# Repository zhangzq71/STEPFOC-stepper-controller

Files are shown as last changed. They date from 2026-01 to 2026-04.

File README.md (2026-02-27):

# STEPFOC Stepper controller

  



## 📖 Project Overview

**STEPFOC** is a FOC based stepper motor controller designed to deliver affordable, high-performance hardware paired with powerful open-source software. Its mission is to transform low-cost stepper motors into high-performance robotic servos, enabling advanced robotics applications without the high price tag.

The controller features a 14-bit magnetic encoder, inline current sensing, CAN and UART interfaces, and supports position, velocity, torque, and impedance control modes.

> [!NOTE]
> Optimized for NEMA17 format but it can also be attached to nema 23 and 14 steppers!

> [!IMPORTANT]
>     **STEPFOC stepper driver is built on the same hardware and software foundation as the Spectral Micro BLDC driver. As a result, some references or images in this documentation may still show the Spectral Micro, since both drivers share about 99% of their features. They also use the same CAN and UART command sets, with only minor differences in UART-based calibration and setup procedures.**

## Where to buy? 

You can buy the STEPFOC stepper controller here: <br />
 https://source-robotics.com/products/stepfoc-stepper-controller

## 💾Firmware 
STEPFOC firmware is located [here](https://github.com/PCrnjak/STEPFOC-stepper-controller/tree/main/STEPFOC%20firmware). To install it follow [this guide!](https://source-robotics.github.io/STEPFOC-docs/flashing_firmware/)

## 📚Documentation:

- [Motor hardware setup guide](https://youtu.be/60UMc95H8iE)
- [Official website](https://source-robotics.com/products/spectral-micro-bldc-controller)
- [DOCS](https://source-robotics.github.io/STEPFOC-docs/) Offers great starting guides with project examples + code 

### API and control
- [GUI software ](https://github.com/PCrnjak/Spectral-motor-GUI)
- [Python API & Examples](https://github.com/PCrnjak/Spectral-BLDC-Python/tree/main)
- [Source Robotics toolbox](https://github.com/PCrnjak/Source-Robotics-Toolbox/tree/main) 

## 🌐 More about STEPFOC drivers

| YouTube | Instagram | Twitter | LinkedIn |
|---|---|---|---|
|  |  |  |  |

| Discord | Forum | Hackaday | Blog |
|---|---|---| ---|
|  |  |  |  

## ⚠️ Safety, Liability & Disclaimer
1. The software and hardware are still in development and may contain bugs, errors, or incomplete features.
2. Users are encouraged to use this software and hardware responsibly and at their own risk.

## 💸Support us

The majority of this project is open source and freely available to everyone. Your assistance, whether through donations or advice, is highly valued. Thank you!

 


## 🛡️ Licensing

Project is under GPLv3 Licence

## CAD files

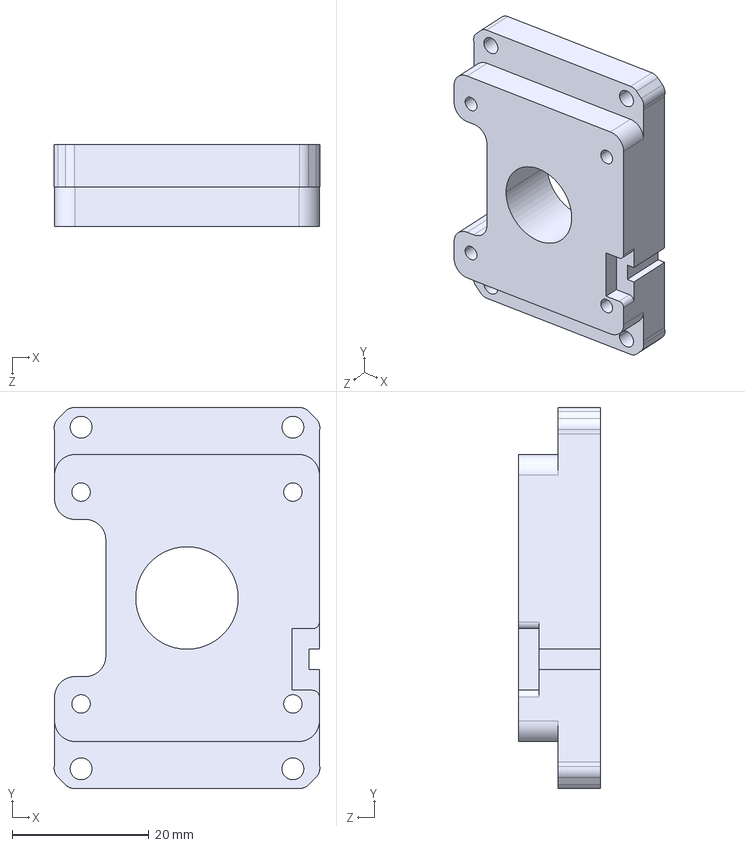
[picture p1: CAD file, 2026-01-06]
STEP files/Stepper motor accessories/NEMA23/NEMA23_stepper_spacer.STEP
38.9 x 55.8 x 12.0 mm

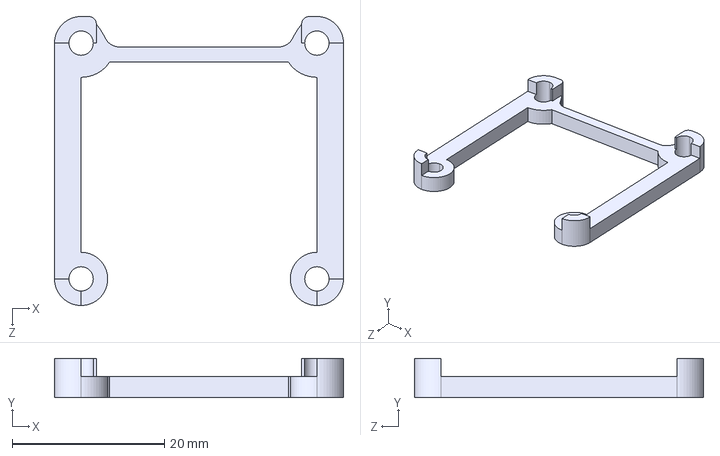
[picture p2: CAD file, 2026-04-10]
STEP files/Stepper motor accessories/Stepper_spacer_NEMA17_21_5mm.STEP
38.0 x 5.15 x 38.0 mm

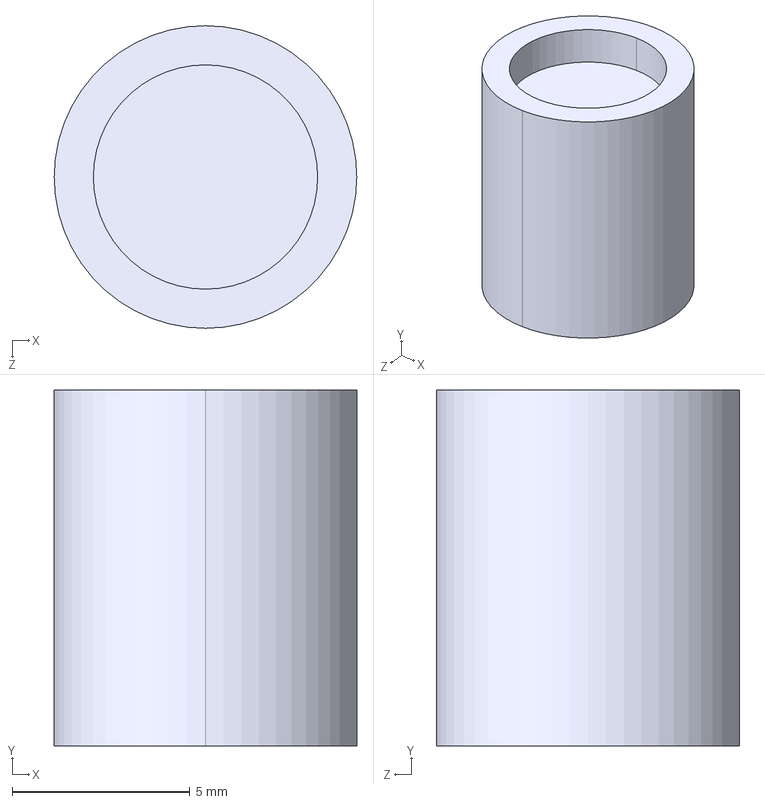
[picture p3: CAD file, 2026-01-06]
STEP files/Tools/Magnet_stepper_tool.STEP
8.50 x 10.0 x 8.50 mm

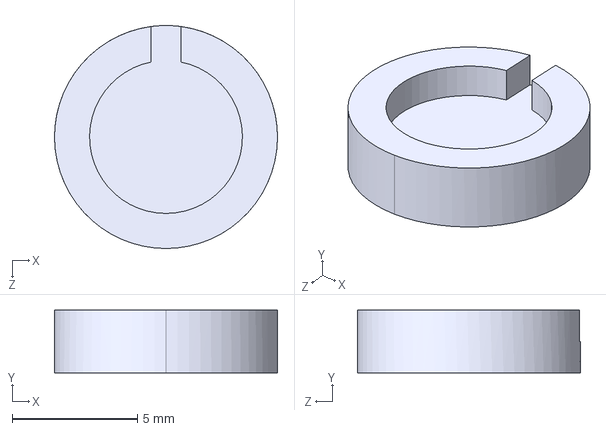
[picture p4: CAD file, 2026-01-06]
STEP files/Stepper motor accessories/Magnet_spacer_2.STEP
8.90 x 2.50 x 8.90 mm

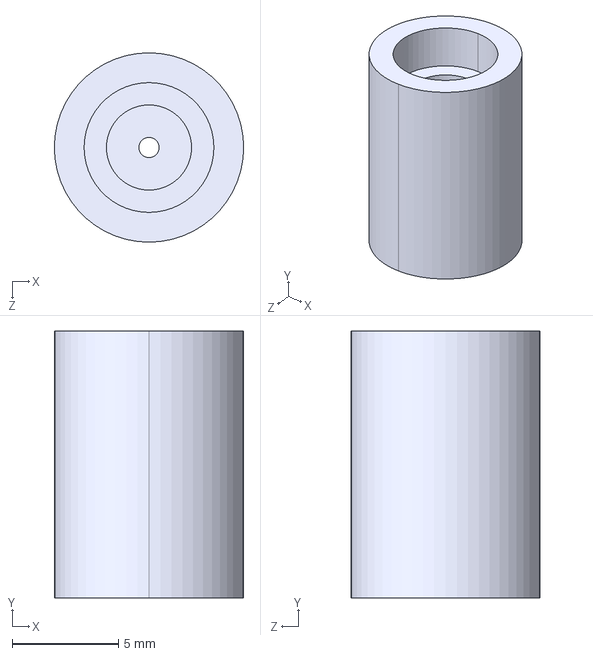
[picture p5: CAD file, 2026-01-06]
STEP files/Stepper motor accessories/NEMA23/Nema23_magnet_spacer.STEP
8.90 x 12.6 x 8.90 mm

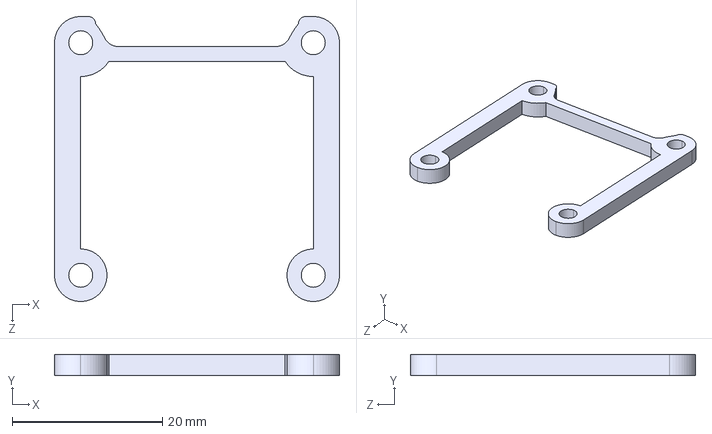
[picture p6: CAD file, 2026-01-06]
STEP files/Stepper motor accessories/Stepper_spacer_NEMA17.STEP
38.0 x 2.80 x 38.0 mm

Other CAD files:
STEP files/Tools/Magnet_stepper_tool_v2.STEP

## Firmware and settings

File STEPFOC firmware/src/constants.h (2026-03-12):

/* USER CODE BEGIN Header */
/**
 ******************************************************************************
 * @file    constants.h
 * @brief   This file provides code where we declare constants
 * @author Petar Crnjak
 ******************************************************************************
 * @attention
 *
 * Copyright (c) Source robotics.
 * All rights reserved.
 *
 * This software is licensed under terms that can be found in the LICENSE file
 * in the root directory of this software component.
 * If no LICENSE file comes with this software, it is provided AS-IS.
 *
 ******************************************************************************
 */

/* Define to prevent recursive inclusion -------------------------------------*/
#ifndef CONSTANTS_H
#define CONSTANTS_H

#define MAX_DRIVE_CURRENT 2800 // 2500 mA

#define MT6816_NO_MAGNET_BIT 0x0002

#define MAX_DUTY 0.95f

#define MIN_DUTY 0.05f

#define OVERMODULATION 1 // 1 no overmodulation, 1.154F SPWM overmodulation

#define ADC_RESOLUTION_ 12

#define MAX_TEMPERATURE 80

#define PI 3.14159265359f

#define PI2 6.283185307f

#define SQRT3DEV2 0.8660254038f

#define CPR 16384

#define RAD_CONST 0.000383495187f

#define CPR2 16384 / 2

#define MIN_VOLTAGE

#define PWM_FREQ 25000

#define LOOP_FREQ 6250 

#define LOOP_TIME 0.00016

#define CLOCK_PRESCALE 14

#define SERIAL_SPEED 256000 // 256000 works, Tested with 1Mbit and works

#define SENSE_RESISTOR 0.025f

#define Rdson 0.2f // 200 miliohms

#define ADC_MIDPOINT 1.65f

#define ADC_MIDPOINT_BIT 2048

#define CURRENT_AMP_GAIN 20

#define R1_voltage 100000

#define R2_voltage 870

#define PWM_MAX 8191

#define PWM_MIN 0

/*
EEPROM CONSTANTS
*/

///// EEPROM variable address list
#define SERIAL_NUMBER_EEPROM 32
#define HARDWARE_VERSION_EEPROM 36
#define BATCH_DATA_EEPROM 40
#define CAN_ID_EEPROM 44
#define SOFTWARE_VERSION_EEPROM 48
#define LED_ON_OFF_EEPROM 52
#define THERMISTOR_ON_OFF_EEPROM 56
#define POLE_PAIR 60
#define DIR_EEPROM 64
#define RESISTANCE_EEPROM 68
#define TOTAL_RESISTANCE_EEPROM 72
#define INDUCTANCE_EEPROM 76
#define KT_EEPROM 80
#define KV_EEPROM 84
#define FLUX_LINKAGE_EEPROM 92
#define KPP_EEPROM 96
#define KPV_EEPROM 100
#define KIV_EEPROM 104
#define VELOCITY_LIMIT_EEPROM 108
#define KIIQ_EEPROM 112
#define KPIQ_EEPROM 116
#define IQ_CURRENT_LIMIT_EEPROM 120

#define KIID_EEPROM 124
#define KPID_EEPROM 128
#define ID_CURRENT_LIMIT_EEPROM 132

#define KP_EEPROM 136
#define KD_EEPROM 140
#define CALIBRATED_EEPROM 144
#define PHASE_ORDER_EEPROM 148
#define WATCHDOG_TIME_EEPROM 152
#define WATCHDOG_ACTION_EEPROM 156
#define HEARTBEAT_RATE_EEPROM 160
#define I_AM_GRIPPER_EEPROM 164
#define RESET_INTEGRAL_EEPROM 168
#define TEMPERATURE_ERROR 172
#define VOLTAGE_ERROR 176
#define VOLTAGE_LIMIT 180
#define THETA_OFFSET 184

/*
CAN BUS CONSTANTS
*/

// OUTPUT CAN command IDs (Commands that spectral driver can send)
#define OUT_HEARTBEAT 9
#define OUT_DATA_PACK_1 3
#define OUT_DATA_PACK_2 5
#define OUT_DATA_PACK_3 7
#define OUT_DATA_HALL 32 // Response to IN_HALL_INDEX

// Commands that host and driver can send. Host only with RTR frame
// Commands that have same command ID on PC and driver side by using REMOTE FRAME
// When beign sent by host they need to be sent as REMOTE FRAME
// BLDC driver then responds with data with SAME ID as the REMOTE FRAME
#define OUT_IN_TEMPERATURE_CAN 23
#define OUT_IN_VOLTAGE_CAN 24
#define OUT_IN_DEVICE_INFO_CAN 25
#define OUT_IN_STATE_OF_ERRORS_CAN 26
#define OUT_IN_IQ 27
#define OUT_IN_ENCODER 28
#define OUT_IN_PING 10
#define OUT_IN_KT 33

// INPUT CAN command IDS (Commands that spectral driver can receive)
// To these commands spectral responds nothing
#define IN_CAN_ID 11
#define IN_ESTOP 0
#define IN_IDLE 12
#define IN_SAVE_CONFIG 13
#define IN_RESET 14
#define IN_CLEAR_ERROR 1
#define IN_WATCHDOG_TIMEOUT 15
#define HEARTBEAT_SETUP 30
#define IN_CYCLIC 29

#define IN_KP_KD 16
#define IN_KIIQ_KPIQ 17
#define IN_KPV_KIV 18
#define IN_KPP 19
#define IN_LIMITS 20
#define IN_IQ 21
#define IN_KT 22

// INPUT CAN command IDS (Commands that spectral driver can receive)
// To these commands spectral responds with specific command ID
#define IN_DATA_PACK_1 2
#define IN_DATA_PACK_2 6
#define IN_DATA_PACK_3 8
#define IN_DATA_PACK_PD 4
#define IN_HALL_INDEX 31


// GRIPPER SPECIFIC COMMANDS
// OUTPUT CAN command IDs (Commands that gripper can send)
#define OUT_GRIPPER_DATA_PACK 60

// INPUT CAN command IDs (Commands that gripper can receive)
#define IN_GRIPPER_DATA_PACK 61
#define IN_GRIPPER_CALIB 62


#endif

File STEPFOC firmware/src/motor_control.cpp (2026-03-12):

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
/* Includes ------------------------------------------------------------------*/

#include "utils.h"
#include <Arduino.h>
#include <stdio.h>
#include "iodefs.h"
#include "hw_init.h"
#include "motor_control.h"
#include "common.h"
#include <SPI.h>
#include "common.h"
#include "foc.h"

#define TIMING_DEBUG 0

SPISettings MT6816_settings(16000000, MSBFIRST, SPI_MODE3);

/// @todo phase order working in any orientation
/// @todo feedforwards for cascade control and PD control
/// @todo cogging compensation
/// @todo encoder non linearity compensation

/// @brief  Collect all sensor data
void Collect_data()
{

  uint16_t result;
  uint16_t result1;
  uint16_t result2;

  /*Get position, current1, current2, vbus*/
  /*position sensor packs its data in 2 8 bit data packets */
  /*First we send 0x8300 as a response we get one packet*/
  /*Then we send 0c8400 as a response we get second packet*/
  /*Between requesting packets we need small delay and we use ADC readings as a delay*/
  /*Reading sense1,2 and vbus takes around 10us */
  /*After we get both packets they are unpacked and we get position value as 14 bit, no mag bit and parity check bit */
  SPI.beginTransaction(MT6816_settings);
  digitalWriteFast(CSN, LOW);
  result1 = SPI.transfer16(0x8300);
  digitalWriteFast(CSN, HIGH);

  controller.Sense1_Raw = ADC_CHANNEL_6_READ_SENSE1();
  controller.Sense2_Raw = ADC_CHANNEL_8_READ_SENSE2();

  controller.VBUS_RAW = ADC_CHANNEL_4_READ_VBUS();
  result1 = result1 << 8;
  digitalWriteFast(CSN, LOW);
  result2 = SPI.transfer16(0x8400);
  digitalWriteFast(CSN, HIGH);
  result = result1 | result2;
  controller.Position_Raw = (result >> 2);
  SPI.endTransaction();
  /***********************************/

  /* Check for magnet on MT6816*/
  if ((result & MT6816_NO_MAGNET_BIT) == MT6816_NO_MAGNET_BIT)
  { // no magnet or not detecting enough flux density
    controller.Magnet_warrning = true;
    controller.encoder_error = 1;
  }
  else
  { // Detected magnet
    controller.Magnet_warrning = false;
  }
  /***********************************/

  /* Parity check, works wierd and inconsistent, skip for now
 if(parityCheck(result)){
    controller.MT6816_parity_check_pass = 1;
 }else{
    controller.MT6816_parity_check_pass = 0;
 }
*/

  /* Transform RAW current and voltage to mV, mA.*/

  controller.Sense1_mA = -Get_current_mA(controller.Sense1_Raw);
  controller.Sense2_mA = Get_current_mA(controller.Sense2_Raw);

  controller.VBUS_mV = Get_voltage_mA(controller.VBUS_RAW);
  /***********************************/

  /* Handle encoder full rotation overflow*/
  if (controller.Position_Raw - controller.Old_Position_Raw > CPR2)
  {
    controller.ROTATIONS = controller.ROTATIONS - 1;
  }
  else if (controller.Position_Raw - controller.Old_Position_Raw < -CPR2)
  {
    controller.ROTATIONS = controller.ROTATIONS + 1;
  }
  /***********************************/

  /* Motor position with multiple rotations in encoder ticks*/
  controller.Position_Ticks = controller.Position_Raw + (controller.ROTATIONS * CPR);
  /***********************************/

  /* Calculate velocity in ticks/s */
  controller.Velocity = (controller.Position_Ticks - controller.Old_Position_Ticks) / LOOP_TIME;
  /* Moving average filter on the velocity */
  controller.Velocity_Filter = movingAverage(controller.Velocity);
  /***********************************/

  /*  Save position values for next cycle*/
  controller.Old_Position_Ticks = controller.Position_Ticks;
  controller.Old_Position_Raw = controller.Position_Raw;
  /***********************************/

  // Position_RAD = qfp_fmul(Position_Raw, RAD_CONST);

  /* Caclculate electrical angle */
  // controller.Electric_Angle = RAD_CONST * fmod((controller.Position_Raw * NPP),CPR);
  controller.Electric_Angle = RAD_CONST * ((controller.Position_Raw * controller.pole_pairs) % CPR);

  // add offset
  controller.Electric_Angle += controller.theta_offset;

  // Normalize angle between 0 and 2Pi
  if (controller.Electric_Angle < 0)
    controller.Electric_Angle = (controller.Electric_Angle + PI2);
  else if (controller.Electric_Angle > PI2)
    controller.Electric_Angle = (controller.Electric_Angle - PI2);
  /***********************************/

  /****  End measurment here *********/
}

/// @brief  Collect all sensor data2
void Collect_data2()
{

  uint16_t result;
  uint16_t result1;
  uint16_t result2;

  /*Get position, current1, current2, vbus*/
  /*position sensor packs its data in 2 8 bit data packets */
  /*First we send 0x8300 as a response we get one packet*/
  /*Then we send 0c8400 as a response we get second packet*/
  /*Between requesting packets we need small delay and we use ADC readings as a delay*/
  /*Reading sense1,2 and vbus takes around 10us */
  /*After we get both packets they are unpacked and we get position value as 14 bit, no mag bit and parity check bit */
  SPI.beginTransaction(MT6816_settings);
  digitalWriteFast(CSN, LOW);
  result1 = SPI.transfer16(0x8300);
  digitalWriteFast(CSN, HIGH);

  controller.Sense1_Raw = ADC_CHANNEL_6_READ_SENSE1();
  controller.Sense2_Raw = ADC_CHANNEL_8_READ_SENSE2();

  controller.VBUS_RAW = ADC_CHANNEL_4_READ_VBUS();
  result1 = result1 << 8;
  digitalWriteFast(CSN, LOW);
  result2 = SPI.transfer16(0x8400);
  digitalWriteFast(CSN, HIGH);
  result = result1 | result2;
  controller.Position_Raw = result >> 2;
  SPI.endTransaction();
  /***********************************/

  /* Check for magnet on MT6816*/
  if ((result & MT6816_NO_MAGNET_BIT) == MT6816_NO_MAGNET_BIT)
  { // no magnet or not detecting enough flux density
    controller.Magnet_warrning = true;
    controller.encoder_error = 1;
  }
  else
  { // Detected magnet
    controller.Magnet_warrning = false;
  }
  /***********************************/

  /* Parity check, works wierd and inconsistent, skip for now
 if(parityCheck(result)){
    controller.MT6816_parity_check_pass = 1;
 }else{
    controller.MT6816_parity_check_pass = 0;
 }
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

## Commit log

2025-12-28 Update README with sale announcement and compatibility info
    Added a note about the product being for sale soon and compatibility with different stepper motor formats.
2026-01-06 added steps
    [Magnet_spacer.STEP, Magnet_spacer_2.STEP, Magnet_stepper_tool.STEP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]
2026-03-12 CAN bus comms extras
    Added CAN bus get_Kt value function.
    Extra function for Hall "detect change on edge"
2026-04-10 update steps
    [Stepper_spacer_NEMA17_21_5mm.STEP]

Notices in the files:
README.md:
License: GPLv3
